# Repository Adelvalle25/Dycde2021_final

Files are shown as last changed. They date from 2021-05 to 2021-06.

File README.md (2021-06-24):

# Dycde2021_final
## Informacion
Este proyecto consiste en la implementación de un sistema de detección de gases en el ambiente por medio de un sensor MQ-135 y medir el nivel de exposicion de cada gas que detecta el gas y una tarjeta de desarrollo NodeMcu que utiliza un chip ESP8266. El envío de los datos se realiza por medio de conexión Wi-Fi hacia la aplicación Blynk. Y se emplemento un ADC de 4 pines digitales para hacer conexiones de mas proyectos.

## Esquematico
### Conexion del ADC Breakouts y MQ-135 a ESP8266
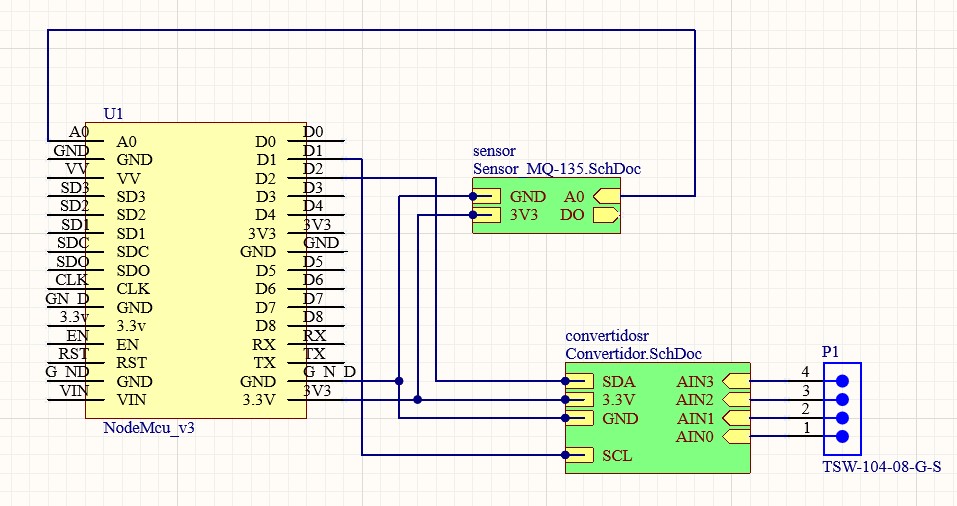
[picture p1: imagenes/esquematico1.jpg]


[logo5]: https://github.com/Adelvalle25/Dycde2021_final/blob/main/imagenes/esquematico1.jpg
### MQ-135
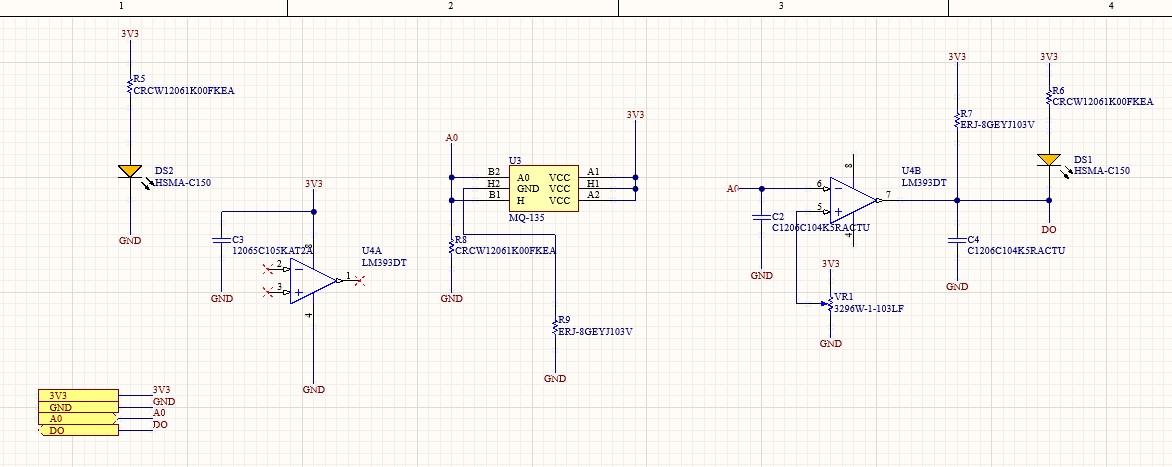
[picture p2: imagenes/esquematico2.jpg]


[logo6]: https://github.com/Adelvalle25/Dycde2021_final/blob/main/imagenes/esquematico2.jpg
### ADC Breakouts
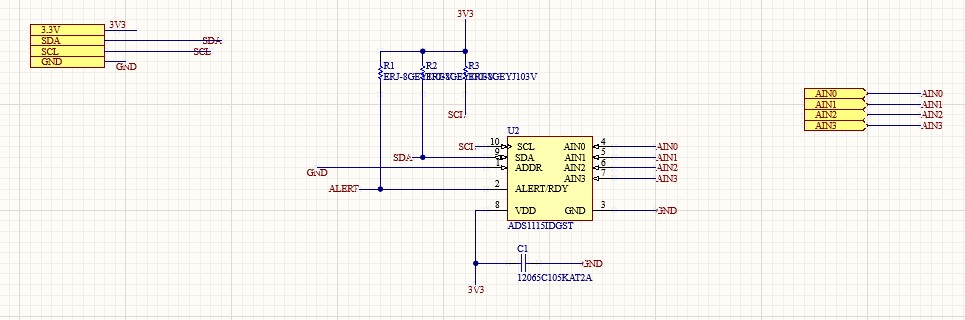
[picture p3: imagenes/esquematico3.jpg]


[logo7]: https://github.com/Adelvalle25/Dycde2021_final/blob/main/imagenes/esquematico3.jpg

## placa fisica
### parte delantera
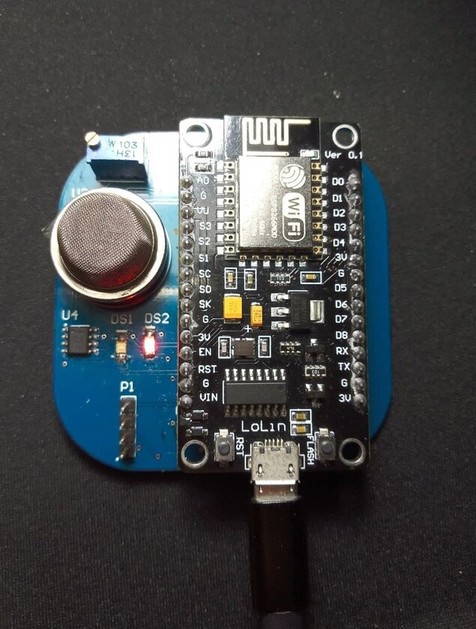
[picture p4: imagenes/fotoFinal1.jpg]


[logo1]: https://github.com/Adelvalle25/Dycde2021_final/blob/main/imagenes/fotoFinal1.jpg " Logo Title Text 2"
### parte trasera
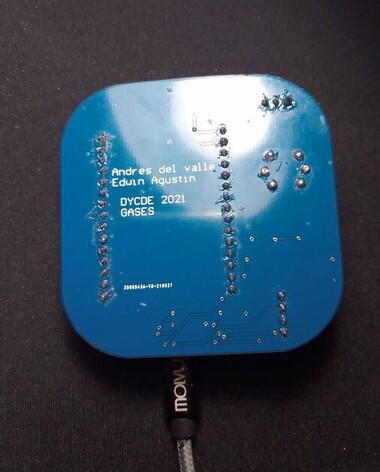
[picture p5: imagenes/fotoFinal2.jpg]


[logo]: https://github.com/Adelvalle25/Dycde2021_final/blob/main/imagenes/fotoFinal2.jpg "Logo Title Text 2"

## PCB 
### parte delantera
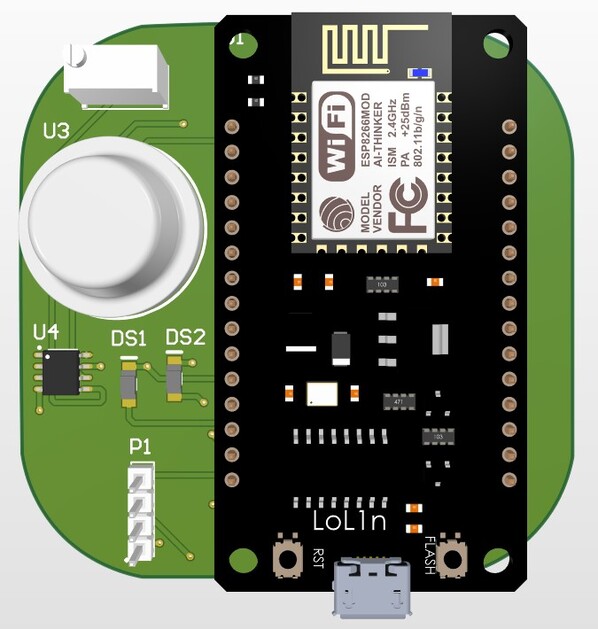
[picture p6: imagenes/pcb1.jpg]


[logo3]: https://github.com/Adelvalle25/Dycde2021_final/blob/main/imagenes/pcb1.jpg
### parte trasera
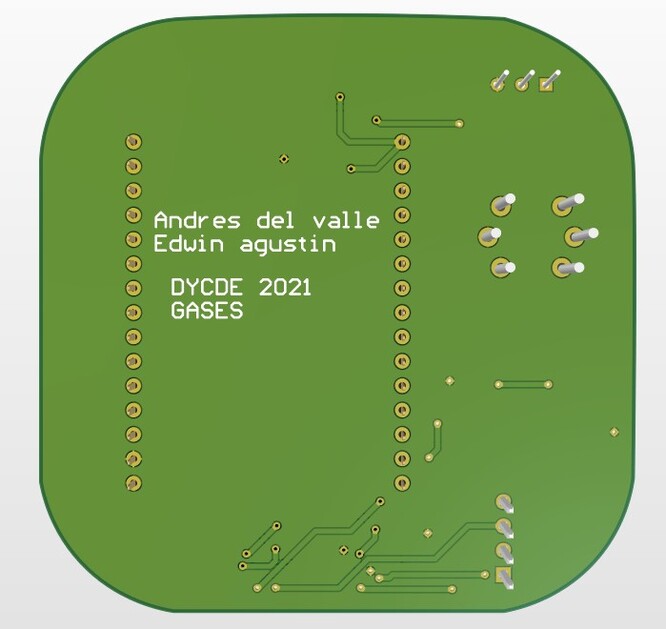
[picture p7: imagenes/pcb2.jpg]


[logo4]:https://github.com/Adelvalle25/Dycde2021_final/blob/main/imagenes/pcb2.jpg

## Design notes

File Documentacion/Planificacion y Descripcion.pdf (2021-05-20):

Nombre: Andres Del Valle, Edwin Agustin

Carné:18005802, 19002814

Curso: Diseño y Construcción de Dispositivos Electrónicos FISICC - UGAL

Fecha: 17 de mayo de 2021

Progreso del proyecto

-elaboración del circuito esquemático ( 20/05 -23/05)

-diseño y generar archivos Gerber (21/05-23/05)

-Se envió el diseño de la PCB a jlcpcb para su fabricación (24/05-30/05)

-ensamblar y probar (31/05-6/06)

-preparación de entrega final Comentarios

- Se usará el sensor mq-135 - Se realizaron pruebas con otros medios

Justificación sensor MQ-135:

En la hoja de datos podemos observar que este sensor es sensible a CO2, Alcohol, Benceno

Según la concentración de estos gases registra un cambio en la resistencia. Se utilizó ya que necesitamos que nos detecte gases peligrosos la idea de un incendio o detector de humo nos llamó la atención de la misma forma un gas peligroso que pueda estar en el ambiente, entonces este sensor tiene varios usos prácticos mientras que los anteriores solo servían para un único proceso, por lo cual para optimizar la PCB utilizamos este sensor. Teníamos la opción de utilizar el MQ811 pero su costo era mayor y tendríamos que mandar a traerlo y el mq135 si esta en las electrónicas de la capital.

Descripción del proyecto

El funcionamiento de nuestro proyecto consistirá en lo siguiente, detectara si hay CO2 en el ambiente (humo) o exceso de alcohol utilizara un protocolo mqtt en el cual podremos monitorear desde cualquier punto que tengamos internet, al detectar cualquiera de estos datos nos enviará una alerta con la opción de producir una alarma con un buzzer que puede ser programable para ser utilizado o no. Esta se puede conectar a un dispositivo Esp8266 por medio de un shield

Dirección del github:

https://github.com/Adelvalle25/Dycde2021_final.git

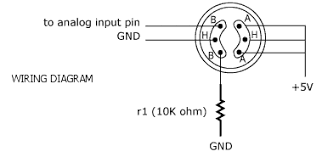
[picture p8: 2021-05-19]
imagenes/MQ-135_PINOUT.png

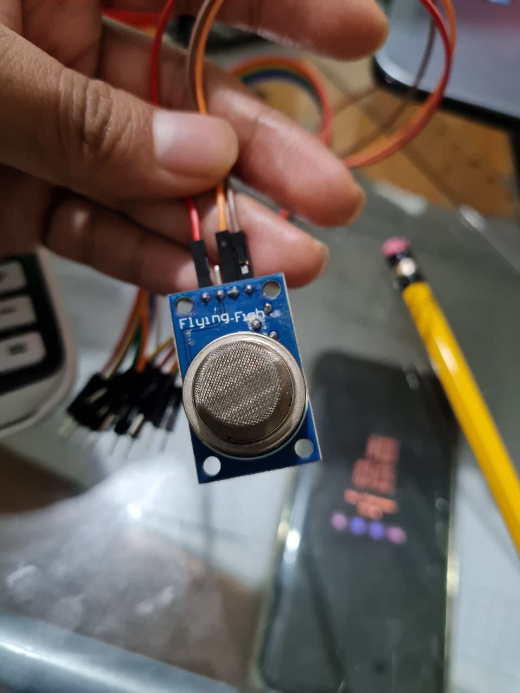
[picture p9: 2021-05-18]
imagenes/mq-135.jpg

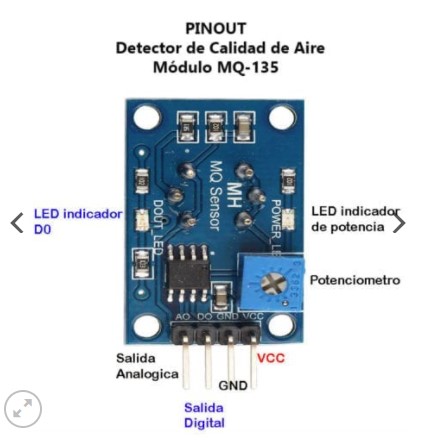
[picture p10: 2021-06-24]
imagenes/module_mq-135.jpg

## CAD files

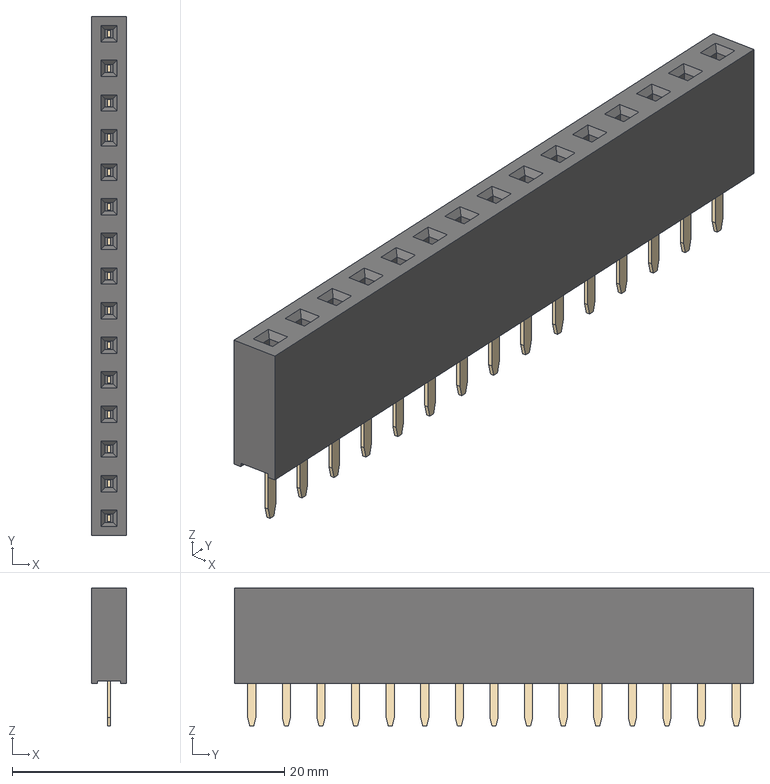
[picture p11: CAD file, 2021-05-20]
altium/Proyecto_DYCDE2021_gases_V1/Recursos/PinSocket_1x15_P2.54mm_Vertical.step
2.54 x 38.1 x 10.1 mm

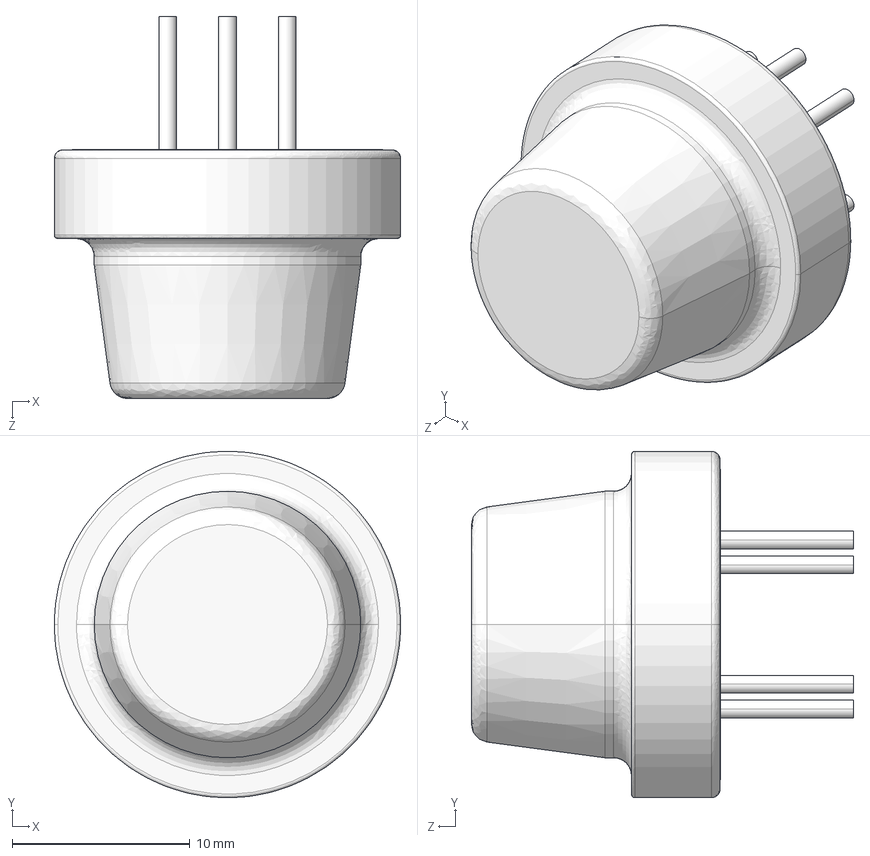
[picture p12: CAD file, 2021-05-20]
altium/Proyecto_DYCDE2021_gases_V1/Recursos/User Library-MQ135.STEP
19.5 x 19.5 x 21.5 mm

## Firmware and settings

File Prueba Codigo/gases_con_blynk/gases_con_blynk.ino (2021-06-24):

#define BLYNK_PRINT Serial
#include <ESP8266WiFi.h>
#include <BlynkSimpleEsp8266.h>
#include <MQUnifiedsensor.h>

//Definitions
#define placa "ESP8266"
#define Voltage_Resolution 5
#define pin A0 //Analog input 0 of your arduino
#define type "MQ-135" //MQ135
#define ADC_Bit_Resolution 10 // For arduino UNO/MEGA/NANO
#define RatioMQ135CleanAir 3.6//RS / R0 = 3.6 ppm  
//#define calibration_button 13 //Pin to calibrate your sensor

//Declare Sensor
MQUnifiedsensor MQ135(placa, Voltage_Resolution, ADC_Bit_Resolution, pin, type);




BlynkTimer timer;
char auth[] = "sZnKemegg0DYo_JSPIhn5FRHYaSdJ2RF";
char ssid[] = "UNE_01E5";
char pass[] = "00002514208087";
int n;
WidgetTerminal terminal(V1);
WidgetTerminal Termi(V2);

void setup()
{
  Serial.begin(9600);
  Blynk.begin(auth, ssid, pass);
  pinMode(16,OUTPUT);
  pinMode(5,OUTPUT);

  terminal.clear();

 MQ135.setRegressionMethod(1); //_PPM =  a*ratio^b
  
  
  MQ135.init(); 
  
  float calcR0 = 0;
  for(int i = 1; i<=10; i ++)
  {
    MQ135.update(); // Update data, the arduino will be read the voltage on the analog pin
    calcR0 += MQ135.calibrate(RatioMQ135CleanAir);
  }
  MQ135.setR0(calcR0/10);
  
  if(isinf(calcR0)) {terminal.println("Warning: Conection issue founded, R0 is infite (Open circuit detected) please check your wiring and supply"); while(1);}
  if(calcR0 == 0){terminal.println("Warning: Conection issue founded, R0 is zero (Analog pin with short circuit to ground) please check your wiring and supply"); while(1);}
}


void loop()
{
  Blynk.run();
  timer.run();
  n=analogRead(A0);
  if(n>190)
  {
     digitalWrite(16,LOW);
    digitalWrite(5,HIGH);   
  }
  if(n<190)
  {
      digitalWrite(16,HIGH);
      digitalWrite(5,LOW);
  }
 MQ135.update(); // Update data, the arduino will be read the voltage on the analog pin

  MQ135.setA(605.18); MQ135.setB(-3.937); // Configurate the ecuation values to get CO concentration
  float CO = MQ135.readSensor(); // Sensor will read PPM concentration using the model and a and b values setted before or in the setup

  MQ135.setA(77.255); MQ135.setB(-3.18); // Configurate the ecuation values to get Alcohol concentration
  float Alcohol = MQ135.readSensor(); // Sensor will read PPM concentration using the model and a and b values setted before or in the setup

  MQ135.setA(110.47); MQ135.setB(-2.862); // Configurate the ecuation values to get CO2 concentration
  float CO2 = MQ135.readSensor(); // Sensor will read PPM concentration using the model and a and b values setted before or in the setup

  MQ135.setA(44.947); MQ135.setB(-3.445); // Configurate the ecuation values to get Tolueno concentration
  float Tolueno = MQ135.readSensor(); // Sensor will read PPM concentration using the model and a and b values setted before or in the setup

  MQ135.setA(102.2 ); MQ135.setB(-2.473); // Configurate the ecuation values to get NH4 concentration
  float NH4 = MQ135.readSensor(); // Sensor will read PPM concentration using the model and a and b values setted before or in the setup

  MQ135.setA(34.668); MQ135.setB(-3.369); // Configurate the ecuation values to get Acetona concentration
  float Acetona = MQ135.readSensor(); // Sensor will read PPM concentration using the model and a and b values setted before or in the setup

  terminal.print("-------------------------------------\n");
  terminal.print("CO: "); terminal.print(CO2 + 400);terminal.print("\n");
  terminal.print("Alcohol: "); terminal.print(Tolueno); terminal.print("\n");
  terminal.print("CO2:  "); terminal.print(NH4); terminal.print("\n");
  terminal.print("Acetona:  "); terminal.print(Acetona);terminal.print("\n");
  terminal.print("-------------------------------------\n");
  Termi.print(1231);
  delay(800);
 

}

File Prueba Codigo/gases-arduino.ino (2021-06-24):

int pin_mq = 2;

void setup() { 
  Serial.begin(9600);
  pinMode(pin_mq, INPUT);
}


void loop() {
  
 
  boolean mq_estado = digitalRead(pin_mq);//Leemos el sensor
  //lee si hay un gas o humo cerca
  if(mq_estado) //si la salida del sensor es 1
  {
    Serial.println("Sin presencia de gas");
  }
  else //si la salida del sensor es 0
  {
    Serial.println("gas detectado");
  }
 
  int adc_MQ = analogRead(A0); //Lemos la salida analógica del MQ
  float voltaje = adc_MQ * (5.0 / 1023.0); //Convertimos la lectura en un valor de voltaje
  
  Serial.print("adc:");
  Serial.print(adc_MQ);
  Serial.print("    voltaje:");
  Serial.println(voltaje);
  delay(1000);
}

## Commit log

2021-05-19 diseño_V1
    [Proyecto_DYCDE2021_gases_V1.PrjPcb]
2021-05-19 mq-135 Schematic design
    [Proyecto_DYCDE2021_gases_V1.PrjPcb, mq-135.SchLib]
2021-05-19 NodeMcu_v3 Schematic Design
    [NodeMcu_v3.SchLib]
2021-05-20 update librerias terminadas
    [MQ-135.PcbLib, NodeMcu_v3.SchLib, PinSocket_1x15_P2.54mm_Vertical.step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]
2021-05-20 librerias terminadas
    [MQ-135.PcbLib, Proyecto_DYCDE2021.SchDoc, Proyecto_DYCDE2021_gases_V1.PrjPcb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]
2021-05-20 update squematics
    [Convertidor.SchDoc, Sensor_MQ-135.SchDoc]
2021-05-20 update squematics and sensors
    [Proyecto_DYCDE2021.SchDoc, Proyecto_DYCDE2021_gases_V1.PrjPcb, Sensor_MQ-135.SchDoc]
2021-05-20 mq135 inicio
    [Proyecto_DYCDE2021.SchDoc, Sensor_MQ-135.SchDoc]
2021-05-20 MQ135 Solo falta colocar los nombres pines
    [Sensor_MQ-135.SchDoc]
2021-05-20 mq135 fin solo nombre pines falta
    [Sensor_MQ-135.SchDoc]
2021-05-20 Convertidor casi terminado
    [Convertidor.SchDoc]
2021-05-20 ultimo del dia
    [Proyecto_DYCDE2021_gases_V1.PrjPcb]
2021-05-20 update schematic
    [Convertidor.SchDoc, Proyecto_DYCDE2021.SchDoc, Sensor_MQ-135.SchDoc]
2021-05-22 unir esquematico general
    [Convertidor.SchDoc, Proyecto_DYCDE2021.SchDoc, Sensor_MQ-135.SchDoc]
2021-05-22 Final Update schematic and create PCB
    [Convertidor.SchDoc, Proyecto_DYCDE2021.PcbDoc, Proyecto_DYCDE2021.SchDoc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]
2021-05-22 Final edit schematic
    [Proyecto_DYCDE2021.SchDoc]
2021-05-22 edit PCB
2021-05-23 Final design
    [Proyecto_DYCDE2021.SchDoc]
2021-05-25 pcb edit and review schematic
    [Convertidor.SchDoc, Proyecto_DYCDE2021.SchDoc, Proyecto_DYCDE2021_gases_V1.PrjPcb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]
2021-05-26 final edits
    [Proyecto_DYCDE2021_gases_V1.PrjPcb]
2021-05-26 final esquematico arreglo
    [Proyecto_DYCDE2021.SchDoc]
2021-05-26 final pcb
2021-06-24 Create PCB final.jpg
2021-06-24 Update PCB final.jpg

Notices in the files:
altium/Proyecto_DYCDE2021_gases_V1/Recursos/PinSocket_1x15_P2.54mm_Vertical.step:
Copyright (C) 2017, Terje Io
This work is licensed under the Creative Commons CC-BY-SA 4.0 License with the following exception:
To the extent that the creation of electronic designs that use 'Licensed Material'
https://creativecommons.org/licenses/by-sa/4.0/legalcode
